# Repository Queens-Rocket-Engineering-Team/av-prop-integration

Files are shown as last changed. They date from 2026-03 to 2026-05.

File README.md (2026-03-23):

# Propulsion Integration Control Boards (Upper, Lower)
> 2025-2026 Season - Propulsion Integration Projects

-  Branch contains both board's **firmware**, **schematics**, and related **documentation and datasheets**.

### Folder Structure
- [`/Schematics`](./Schematics/) : PCB design files (KiCad V8)  
- [`/Firmware`](./Firmware/) : Arduino C/C++ code 
- [`/Datasheets`](./Datasheets/) : Datasheets and reference materials  

---

**Branch Created by:** Jeevan Sanchez

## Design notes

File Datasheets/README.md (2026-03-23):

# LC Board Datasheets

This directory contains datasheets, reference documents, and technical notes for LC board components, including:

- ESP32 MCU

- any interfaced hardware (sensors, CAN transceiver, etc.)

- software docs (external libs, etc.)

Filenames should follow the template: **`<type>_<partnumber>_<doc_type>`**, where **`<doc_type>`** indicates the document kind (e.g., `DS` = Datasheet, `DC` = Document, `C` = Chart).

- more documentation/notes/research can be found on the <a  href="https://www.notion.so/native/qret-ohyeah/Propulsion-Integration-Projects-261401792b9b805eae9ad54960dac8c4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">Notion<a/>

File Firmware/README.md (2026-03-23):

# Propulsion Integration Boards Firmware

This directory contains the firmware for both prop. integration boards. 

Including:

- board-specific firmware (testing, WiFi)
- shared firmware

 Firmware is developed in Arduino C/C++.

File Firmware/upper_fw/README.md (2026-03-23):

# Upper Board (Pheonix) Firmware

> This directory contains the firmware for the *upper* launch control board.

- Written in Arduino C/C++

---

### Configuring Arduino environment for ESP32-S3
 Ensure your [Arduino IDE](https://support.arduino.cc/hc/en-us/articles/360019833020-Download-and-install-Arduino-IDE) is up-to-date. 
- Open the *Preferences* menu (Ctrl+Comma), and add the link below into the *Additional Boards Manager* field. 
https://espressif.github.io/arduino-esp32/package_esp32_index.json 

- Navigate to the *Boards Manager* (Ctrl+Shift+B), and download the package **esp32** by **Espressif Systems**. 
- Once installed, open the *Tools* menu, and select the *Board* field, under the library you just installed (esp32), select the board: **ESP32S3 Dev Module**. 
- After selecting your board, you will see more fields under the *Tools* menu, find the field **USB CDC On Boot**, and **ENABLE** it. 
- Make sure you've selected the corrected port and upload!

### ADC Library used for reading from the onboard ADS131M04.
> https://github.com/icl-rocketry/ADS131M04-Lib/tree/master

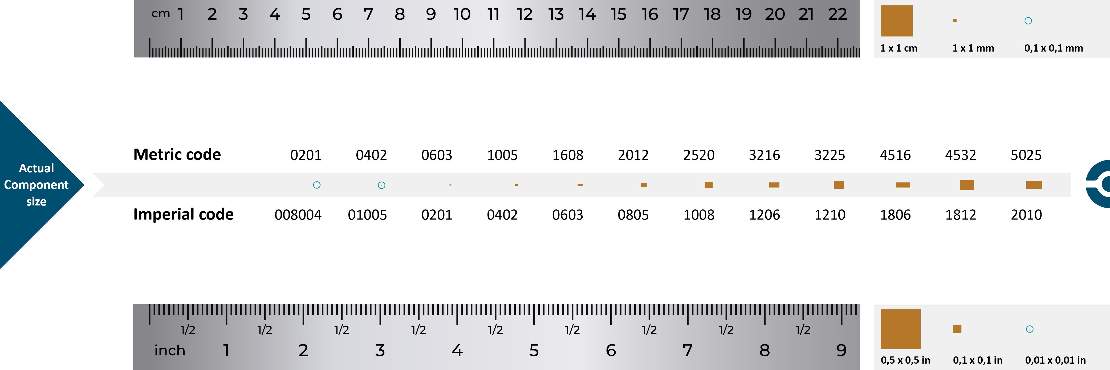
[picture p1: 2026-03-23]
Datasheets/SMD_SIZECHART_C.jpg

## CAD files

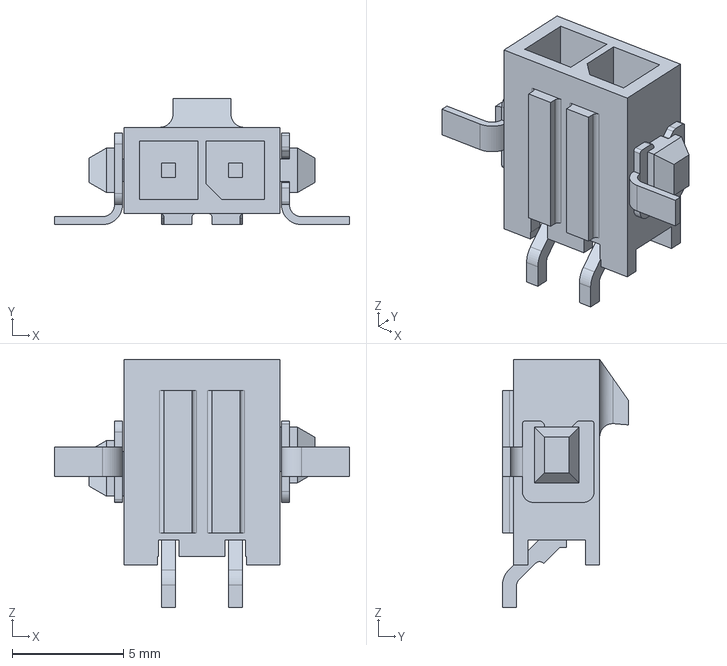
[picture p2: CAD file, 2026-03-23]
Schematics/dummy_24v_board/models/CONN_2-1445057-2_AMP.step
13.2 x 5.67 x 11.2 mm

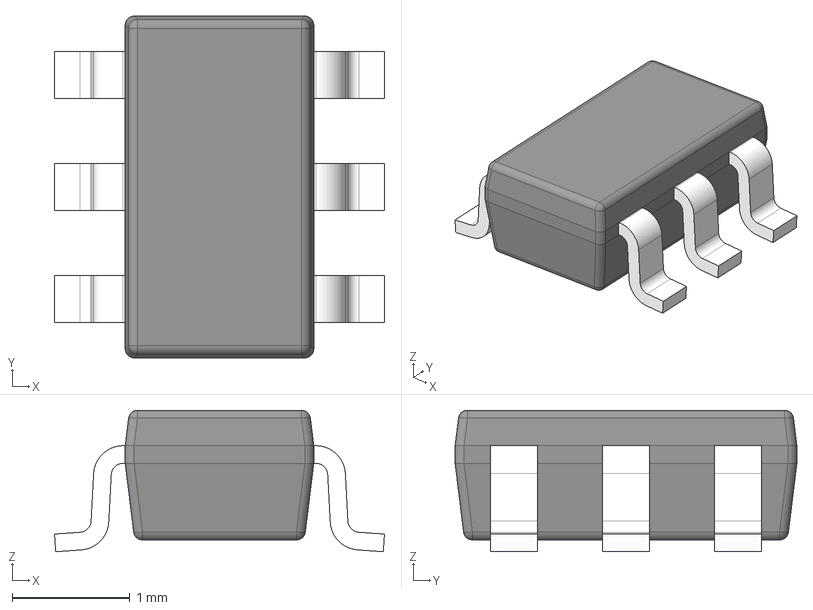
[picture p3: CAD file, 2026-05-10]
Schematics/hall_effect_board/models/TMAG5273A1QDBVT.stp
2.80 x 2.90 x 1.20 mm
BODY-SOT
LEAD-SOT x 6

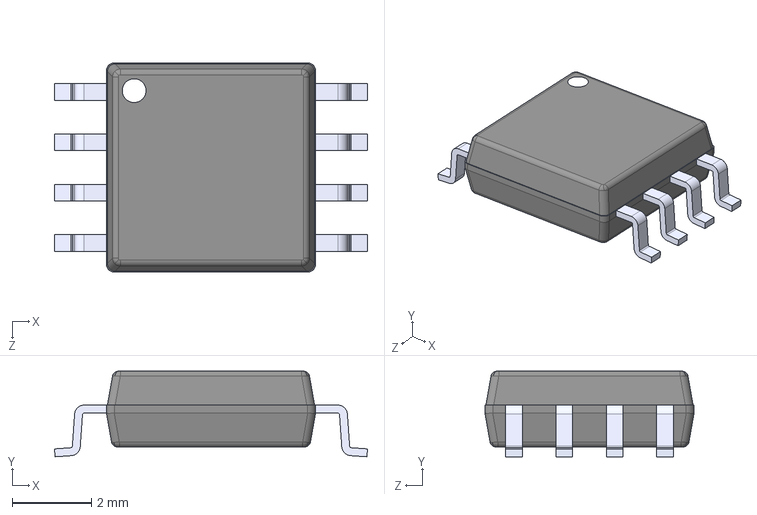
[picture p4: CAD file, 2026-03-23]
Schematics/lower_lc_board/models/W25Q128JVSIM.step
7.90 x 2.16 x 5.28 mm

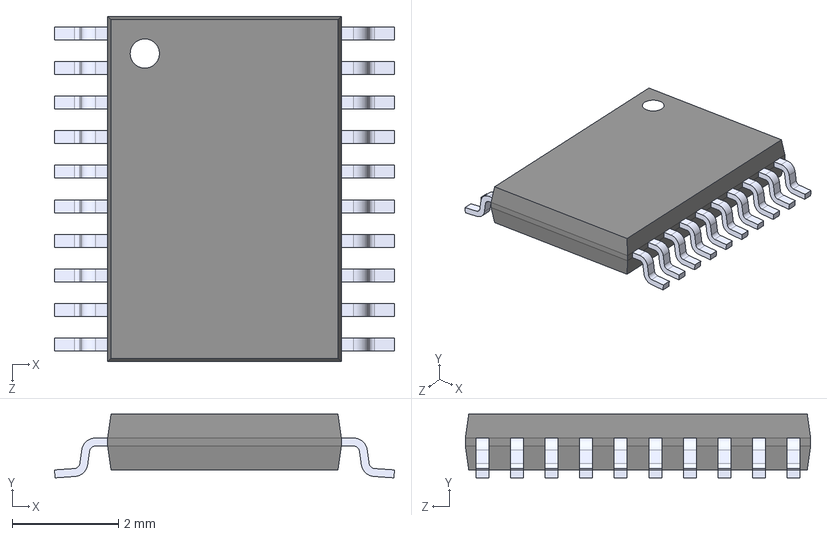
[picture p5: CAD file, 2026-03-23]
Schematics/shared_schematics/models/ADS131M04IPWR.step
6.40 x 1.20 x 6.50 mm

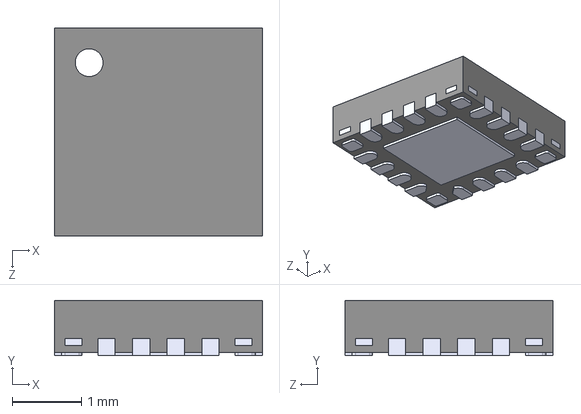
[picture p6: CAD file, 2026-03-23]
Schematics/lower_lc_board/models/CP2102N-A02-GQFN20.STEP
3.00 x 0.8 x 3.00 mm

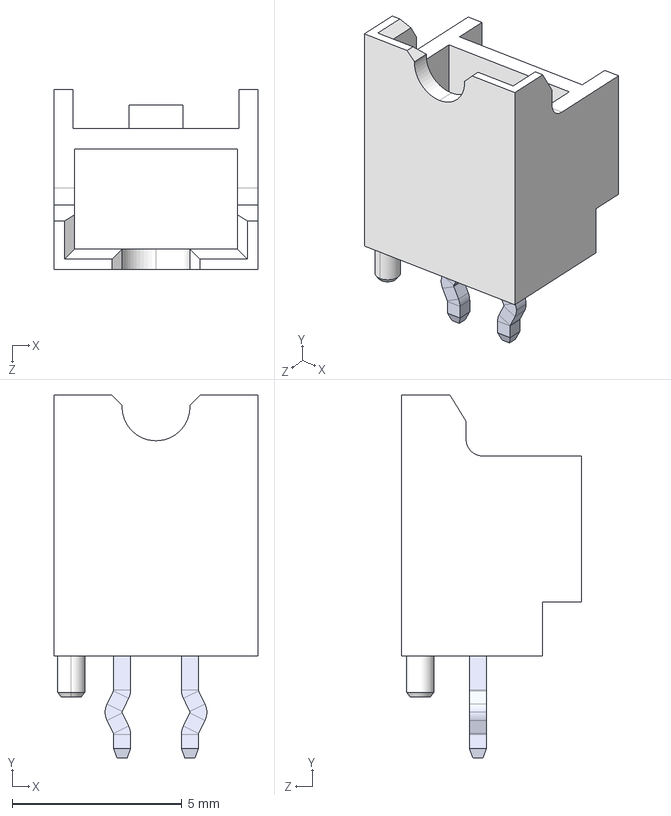
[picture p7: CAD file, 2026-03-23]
Schematics/lower_lc_board/models/B02B-PASK-1.STEP
6.00 x 10.7 x 5.30 mm
BxB-PASK(1)2-9_2boss
pin_bent x 2

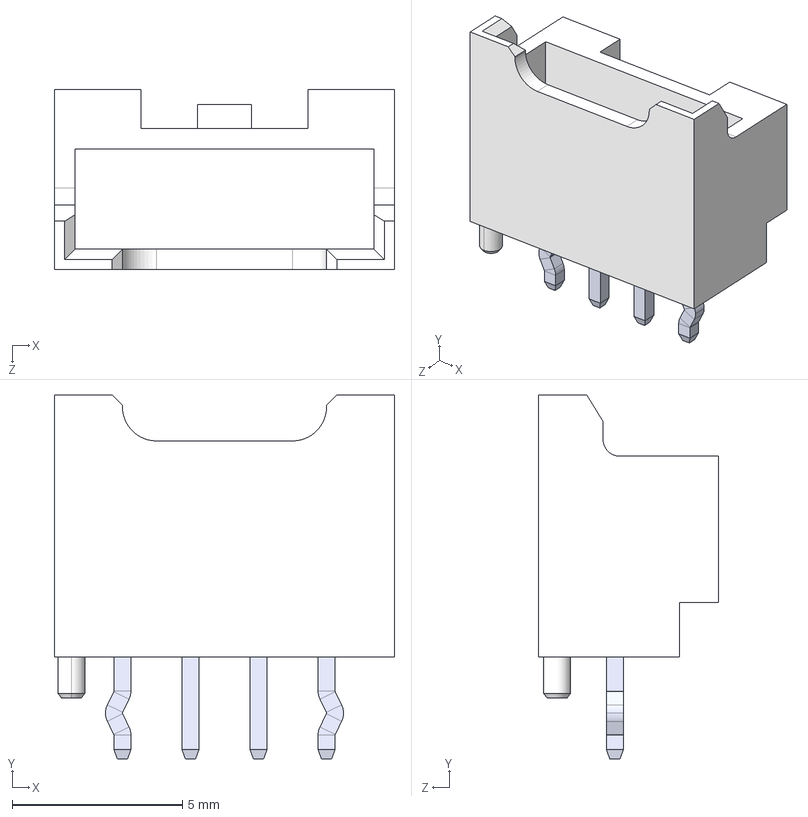
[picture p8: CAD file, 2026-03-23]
Schematics/lower_lc_board/models/B04B-PASK-1.STEP
10.00 x 10.7 x 5.30 mm
BxB-PASK(1)2-9_4boss
pin_bent x 2
pin x 2

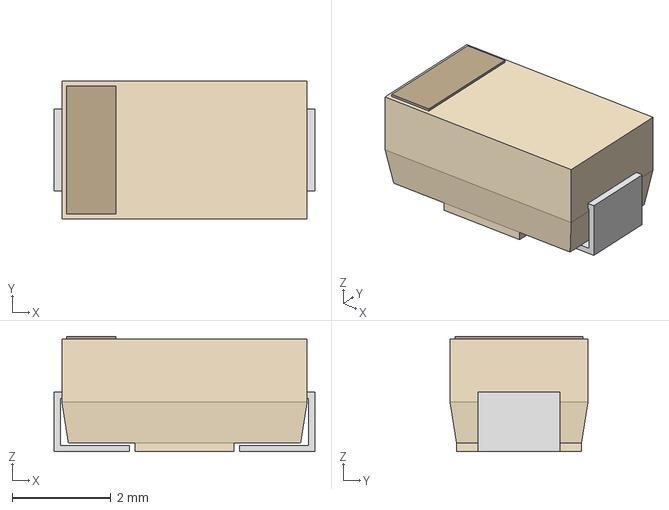
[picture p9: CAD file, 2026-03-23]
Schematics/shared_schematics/models/SMASeries_LTF.step
5.28 x 2.79 x 2.34 mm

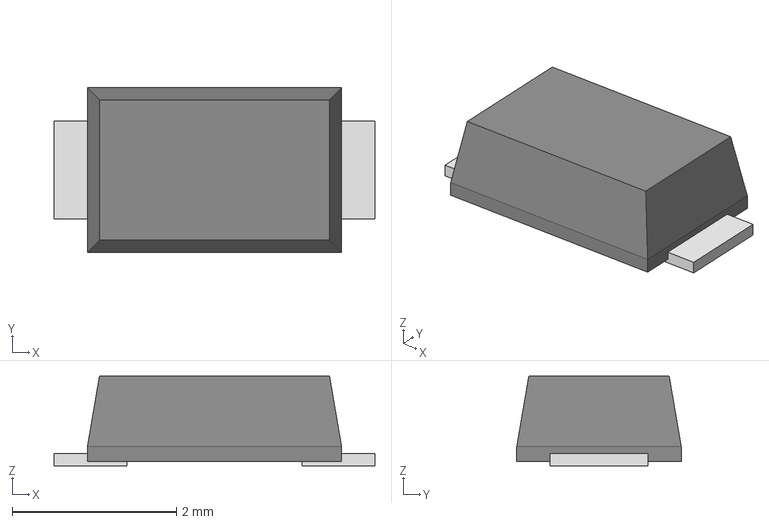
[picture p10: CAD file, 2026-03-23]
Schematics/shared_schematics/models/SOD-123F_LTF.step
3.91 x 2.01 x 1.09 mm

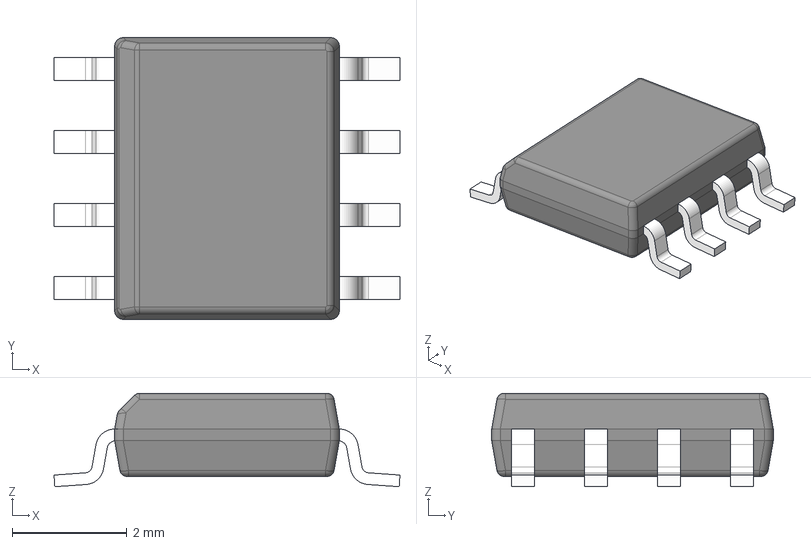
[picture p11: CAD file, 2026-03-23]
Schematics/shared_schematics/models/D0008A.stp
6.02 x 4.90 x 1.63 mm
BODY-SO
LEAD-D0008A x 8

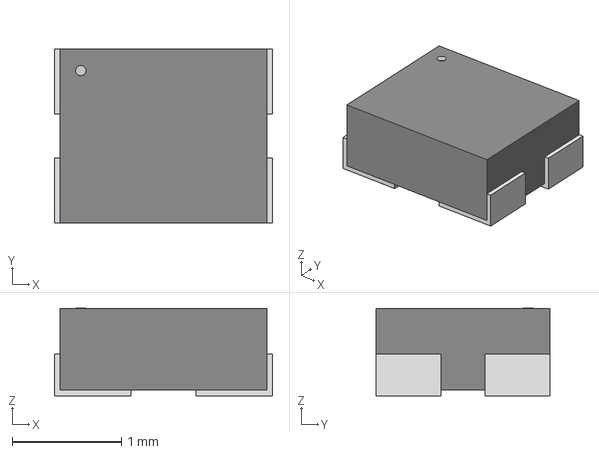
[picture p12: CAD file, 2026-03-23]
Schematics/shared_schematics/models/SON4_SIT1602-7_SIT.step
2.00 x 1.60 x 0.803 mm

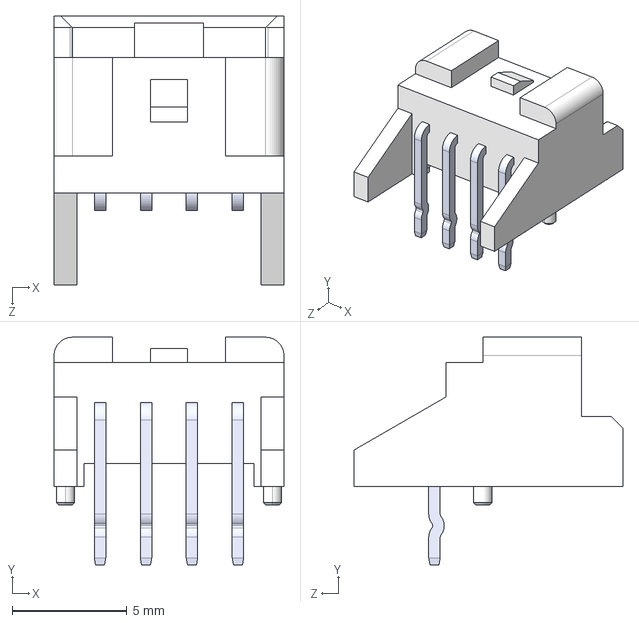
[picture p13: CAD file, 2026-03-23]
Schematics/shared_schematics/models/S04B-PASK-2.STEP
10.0 x 9.90 x 11.7 mm

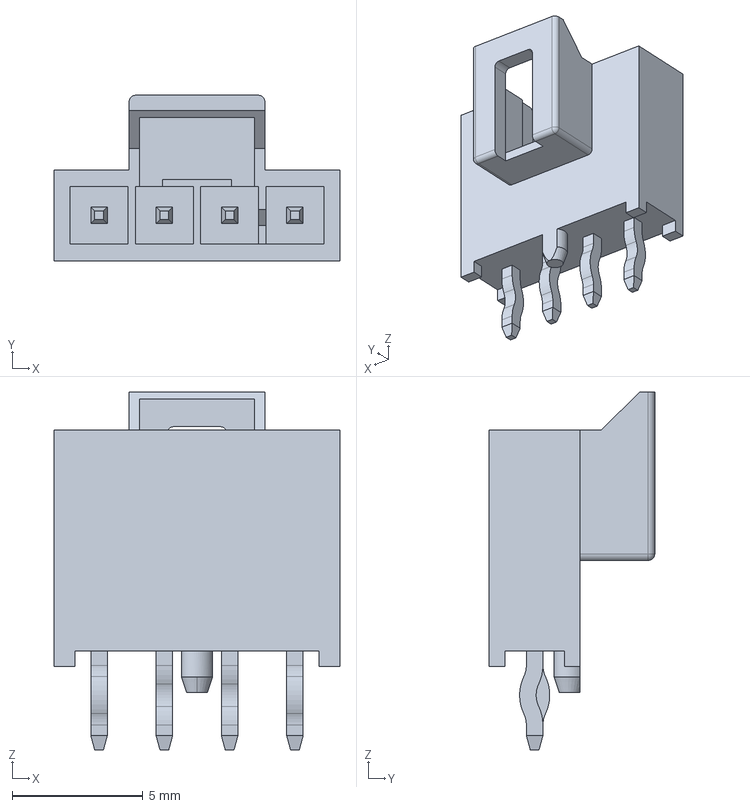
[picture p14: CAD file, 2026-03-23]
Schematics/hall_effect_board/models/1053091104.stp
10.9 x 6.34 x 13.7 mm

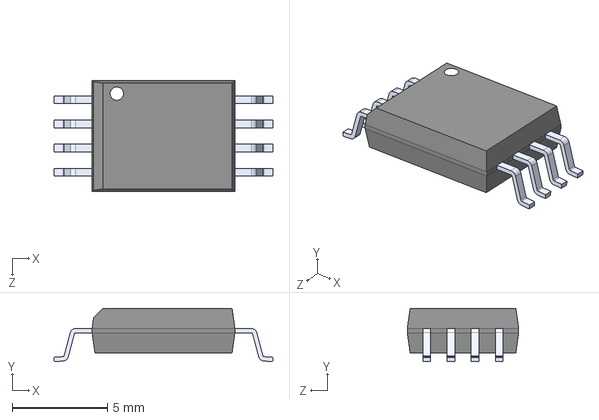
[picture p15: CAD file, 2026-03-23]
Schematics/shared_schematics/models/ISO1042BDWVR.step
11.5 x 2.80 x 5.85 mm

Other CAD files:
Schematics/lower_lc_board/models/m20-8890445r.stp
Schematics/shared_schematics/models/1053131102.step
Schematics/shared_schematics/models/1053091102.step
Schematics/lower_lc_board/models/430450602.stp
Schematics/shared_schematics/models/0679L0250-05.step
Schematics/shared_schematics/models/1053131104.stp
Schematics/shared_schematics/models/430450212.step
Schematics/shared_schematics/models/LM66100DCKR.STEP

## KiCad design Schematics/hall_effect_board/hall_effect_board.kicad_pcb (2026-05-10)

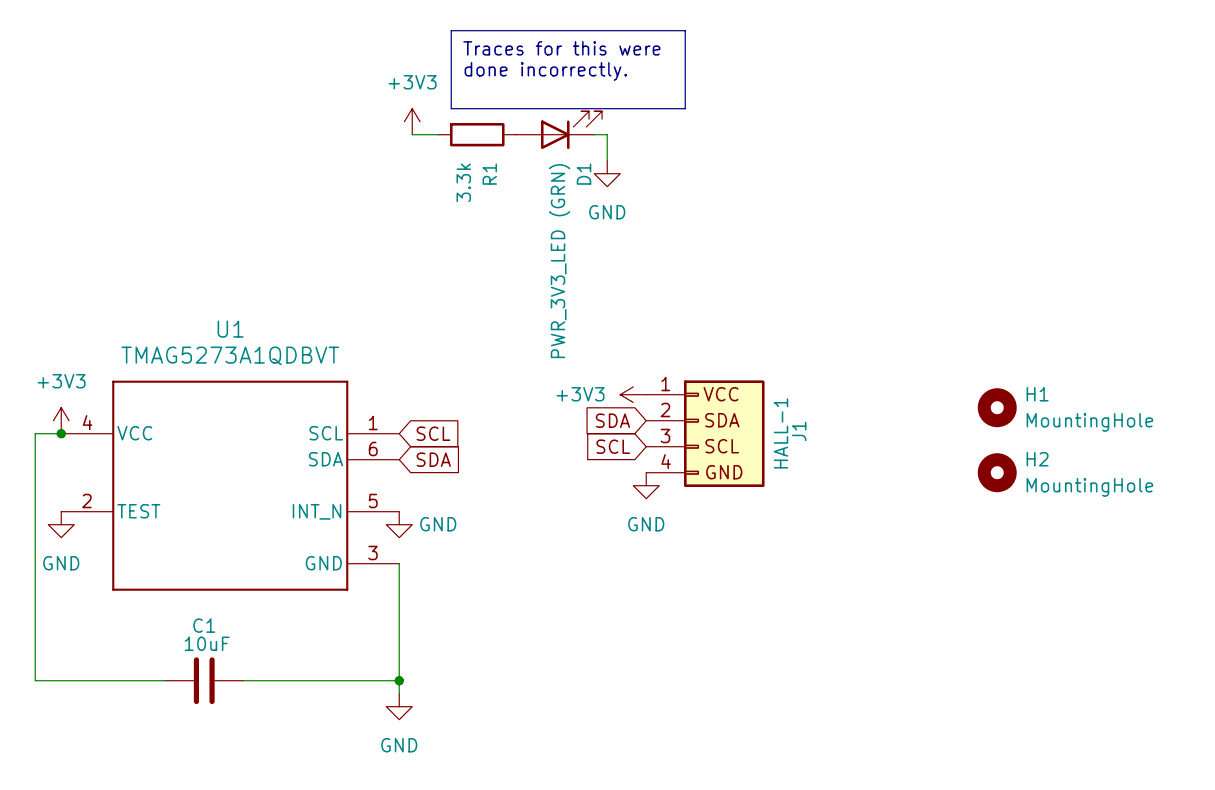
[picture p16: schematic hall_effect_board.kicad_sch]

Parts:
C1: 10uF; C_0805_2012Metric_Pad1.18x1.45mm_HandSolder; JLCSC C15850
D1: PWR_3V3_LED (GRN); LED_0603_1608Metric; JLCSC C2297
H1, H2: MountingHole; MountingHole_3.2mm_M3_ISO14580_Pad
J1: HALL-1; Molex_Nano-Fit_105313-xx04_1x04_P2.50mm_Horizontal; Digikey 455-S04B-PASK-2-ND
R1: 3.3k; R_0603_1608Metric; JLCSC C22978
U1: TMAG5273A1QDBVT; DBV0006A-IPC_A; Digikey 296-TMAG5273A1QDBVTCT-ND

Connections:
+3V3: C1.1, J1.1, R1.2, U1.4 (VCC)
GND: C1.2, D1.1 (K), J1.4, U1.2 (TEST), U1.3 (GND), U1.5 (INT_N)
unnamed: D1.2 (A), R1.1
SCL: J1.3, U1.1 (SCL)
SDA: J1.2, U1.6 (SDA)

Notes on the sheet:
Traces for this were done incorrectly.

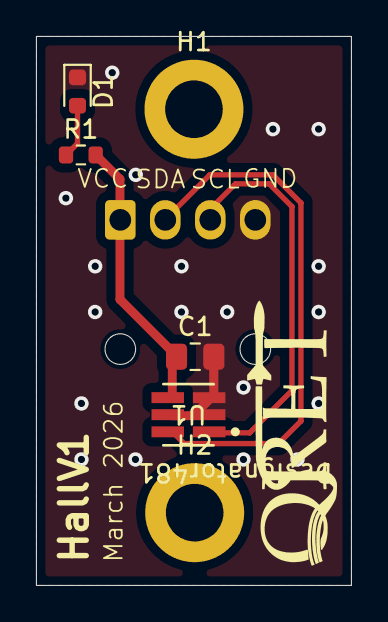
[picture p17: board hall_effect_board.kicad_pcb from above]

Board: 2 copper layers, 17.5 x 30.5 mm, 7 parts (1 on the bottom side), 5 nets.

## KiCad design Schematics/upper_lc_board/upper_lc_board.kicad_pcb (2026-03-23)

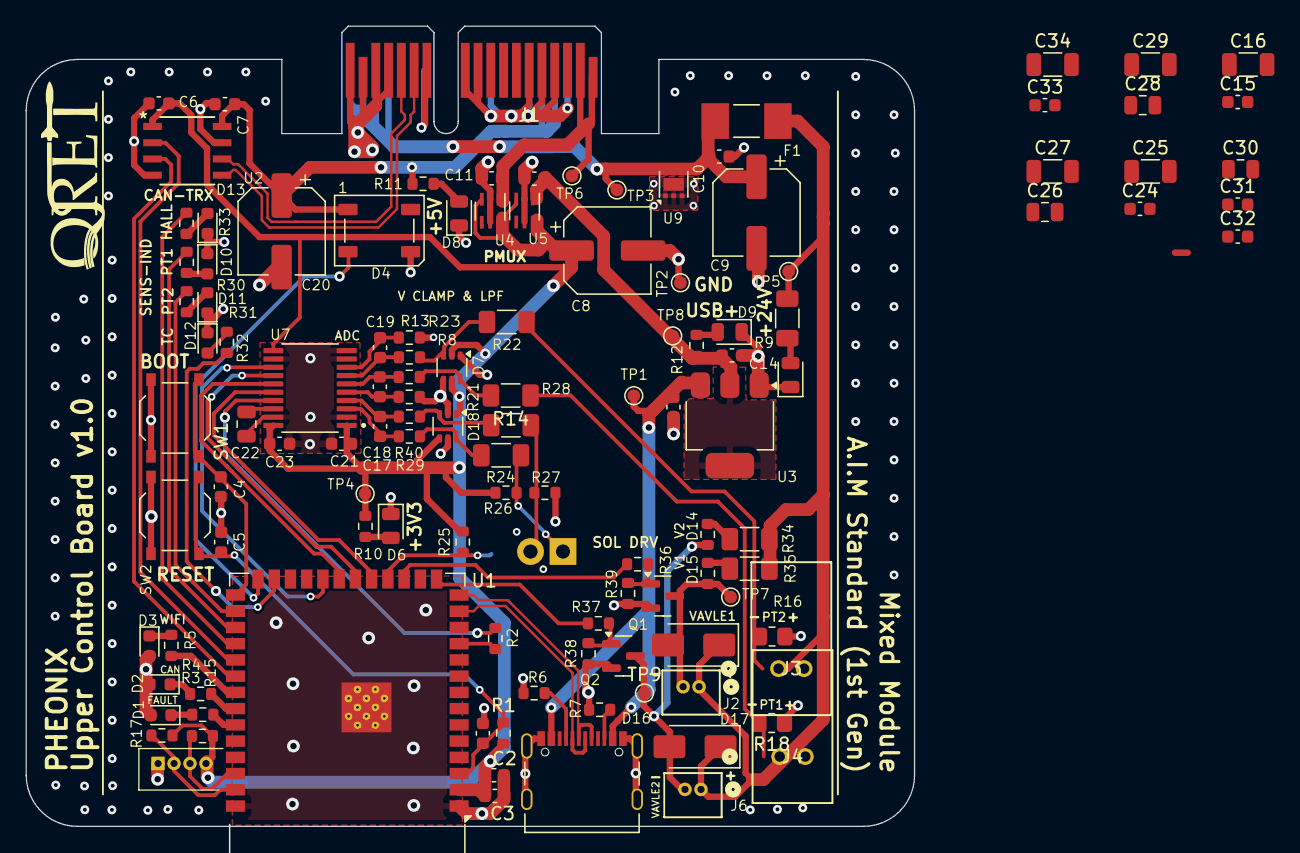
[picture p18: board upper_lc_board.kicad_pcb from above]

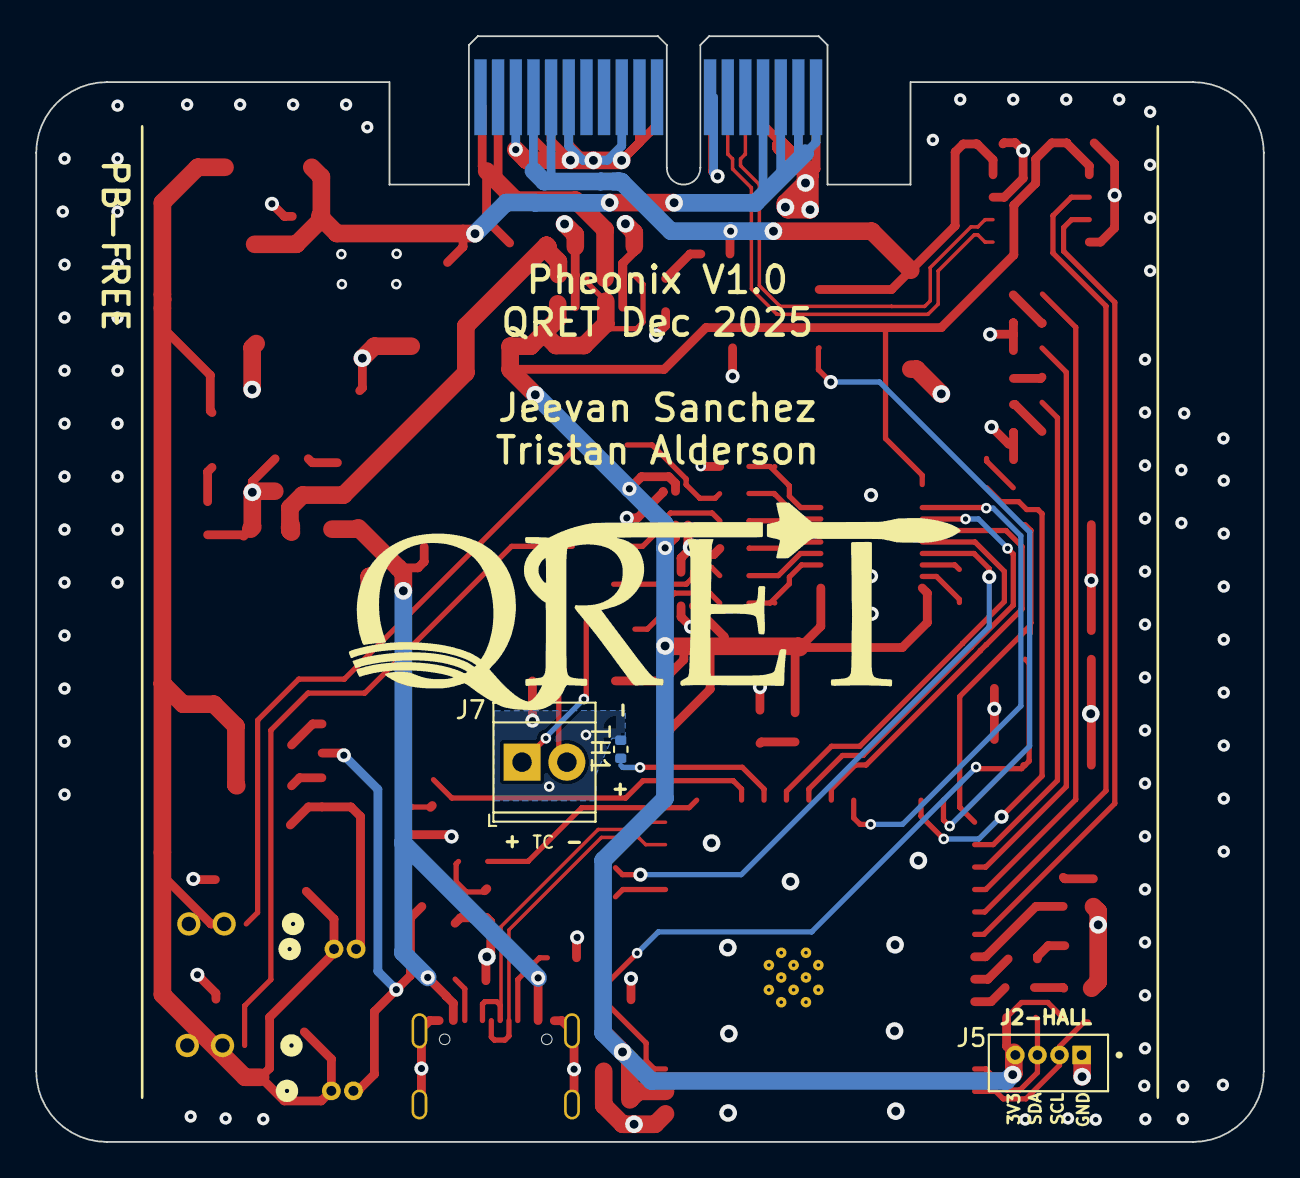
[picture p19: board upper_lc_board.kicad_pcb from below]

Board: 4 copper layers, 69.5 x 62.6 mm, 121 parts (3 on the bottom side), 73 nets.

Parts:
C1, C11, C12, C21, C23: 1uF; C_0603_1608Metric
C2, C4, C5, C6, C7, C10, C33: 0.1uF; C_0603_1608Metric
C3, C13, C14: 10uF; C_0603_1608Metric
C8, C9, C20: 100uF; CP_Elec_6.3x5.9
C15, C24: 0.1uF_50V; C_0603_1608Metric
C16, C25: 10uF_50V; C_1206_3216Metric
C17, C18, C19: 10nF; C_0603_1608Metric
C22: 220 nF; C_0805_2012Metric
C26, C28, C30: 0.1uF; C_0805_2012Metric
C27, C29: 10uF; C_1206_3216Metric
C31, C32: 1nF; C_0603_1608Metric
C34: 1uF_10V; C_1206_3216Metric
D1: FAULT_LED; LED_0603_1608Metric
D2: CAN_LED; LED_0603_1608Metric
D3: WIFI_LED; LED_0603_1608Metric
D4: SYS_LED_WS2812B; LED_WS2812B_PLCC4_5.0x5.0mm_P3.2mm
D5: PWR_24V_LED (GRN); LED_0805_2012Metric
D6: PWR_3V3_LED (GRN); LED_0805_2012Metric
D7, D18: BAV199DW; SOT-363_SC-70-6
D8: PWR_5V_LED (GRN); LED_0805_2012Metric
D9: USB_LED (GRN); LED_0805_2012Metric
D10, D11, D12, D13: LED; LED_0603_1608Metric
D14: SOL2_LED (YELW); R_0603_1608Metric
D15: SOL1_LED (YELW); R_0603_1608Metric
D16, D17: SS34; D_SMA
F1: Fuse; FUSC6125X279N
J1: Stack Male Edge Connector; BUS_PCIexpress_x1
J2, J6: SOL_CONN; CONN02_530470260_MOL
J3, J4: PT1; CONN2_S02B-PASK-2_JST
J5: HALL; MOLEX_53047-0460
J7: Screw_Terminal_01x02; TerminalBlock_TE_282834-2_1x02_P2.54mm_Horizontal
J8: USB_C_Female_USB2_Small; USB_C_DB-108PWB
NT1: GND-TIE; NetTie-2_SMD_Pad0.5mm
Q1, Q2: AO3400A; SOT-23
R1, R25: 10k; R_0603_1608Metric
R2: 33; R_0603_1608Metric
R3, R4, R5, R10, R12, R30, R31, R32, R33: 150; R_0603_1608Metric
R6, R7: 5.1k; R_0603_1608Metric
R8, R13, R29, R36, R37, R40: 200; R_0603_1608Metric
R9, R34, R35: 4.7k; R_1206_3216Metric_Pad1.30x1.75mm_HandSolder
R11: 510; R_0603_1608Metric
R14, R22, R24, R28: 1k; R_1206_3216Metric_Pad1.30x1.75mm_HandSolder
R15, R17: 2.2k; R_0603_1608Metric
R16, R18: 165; R_0805_2012Metric_Pad1.20x1.40mm_HandSolder
R21, R23: 1.2k; R_0603_1608Metric
R26, R27: 1M; R_0603_1608Metric
R38, R39: 100k; R_0603_1608Metric
SW1: SW_ESP_BOOT_MODE; SW_Push_1P1T_XKB_TS-1187A
SW2: SW_ESP_RESET; SW_Push_1P1T_XKB_TS-1187A
TH1: Thermistor; R_0402_1005Metric
TP1: 5V_USB; TestPoint_Pad_D1.0mm
TP2: GND; TestPoint_Pad_D1.0mm
TP3: 24V_BP; TestPoint_Pad_D1.0mm
TP4: 3V3; TestPoint_Pad_D1.0mm
TP5: 24V; TestPoint_Pad_D1.0mm
TP6: 3V3_BP; TestPoint_Pad_D1.0mm
TP7: VALVE1_OUT_TP; TestPoint_Pad_D1.0mm
TP8: 3V3_USB; TestPoint_Pad_D1.0mm
TP9: VALVE2_OUT_TP; TestPoint_Pad_D1.0mm
U1: ESP32-S3-WROOM-1-N16; ESP32-S3-WROOM-1
U2: ISO1044BDR; SOIC_1044BDR_TEX
U3: AMS1117; SOT-223-3_TabPin2
U4, U5: ID_LM66100DCKR; SC-70-6
U7: ADC_ADS131M04IPWR; SOP65P640X120-20N
U9: TVS3300DRV; WSON-6-1EP_2x2mm_P0.65mm_EP1x1.6mm

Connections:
5V_USB: C13.1, J8.A4 (VBUS), J8.A9 (VBUS), J8.B4 (VBUS), J8.B9 (VBUS), TP1.1, U3.3 (VI)
+3V3: C2.1, C3.1, C6.1, C8.1, C21.2, C23.2, C33.1, C34.1, D7.2 (K2), D7.5 (K4), D18.2 (K2), D18.5 (K4), J5.4, R1.1, R10.2, R15.2, R17.1, R25.2, R26.1, TP4.1, U1.2 (3V3), U2.1 (VCC1), U4.3 (*CE), U4.6 (VOUT), U5.3 (*CE), U5.6 (VOUT), U7.1 (AVDD), U7.11 (~SYNC/~RESET), U7.20 (DVDD)
+5V: C7.1, C20.1, D4.1 (VDD), J1.A4 (5.0V_A), J1.A5 (5.0V_A), R11.2, U2.8 (VCC2)
+24V: C15.1, C16.1, C24.1, C25.1, D16.1 (K), D17.1 (K), F1.1, J2.1, J6.1, R9.2, R34.2, R35.2, TP5.1
+24V_BP: C10.1, J1.A15 (24V_C), J1.A16 (24V_C), J1.A17 (24V_C), J1.A18 (24V_C), TP3.1, U9.4 (IN), U9.5 (IN), U9.6 (IN)
/ESP Breakout Cirucitry/ESP32_EN: C1.1, C5.2, R1.2, SW2.2, U1.3 (EN)
/ESP Breakout Cirucitry/ESP32_IO0: C4.2, SW1.2, U1.27 (IO0)
/ESP Breakout Cirucitry/GPIO_18: R2.1, U1.11 (IO18)
/ESP Breakout Cirucitry/GPIO_38: U1.31 (IO38), U2.2 (TXD)
/ESP Breakout Cirucitry/GPIO_39: U1.32 (IO39), U2.3 (RXD)
/ESP Breakout Cirucitry/GPIO_40: R5.1, U1.33 (IO40)
/ESP Breakout Cirucitry/GPIO_41: R4.1, U1.34 (IO41)
/ESP Breakout Cirucitry/GPIO_42: R3.1, U1.35 (IO42)
/ESP Breakout Cirucitry/GPIO_45: D4.2 (DOUT), U1.26 (IO45)
/ESP Breakout Cirucitry/USB_N: J8.A7 (D-), J8.B7 (D-), U1.13 (USB_D-)
/ESP Breakout Cirucitry/USB_P: J8.A6 (D+), J8.B6 (D+), U1.14 (USB_D+)
/Power Circuitry/3V3_BP: C11.2, J1.A1 (3.3V_A), J1.A2 (3.3V_A), TP6.1, U4.1 (VIN)
/Power Circuitry/3V3_USB: C12.1, C14.1, R12.1, TP8.1, U3.2 (VO), U5.1 (VIN)
/Sensor Circuitry/PT1: J4.2, R14.1, R18.2
/Sensor Circuitry/PT1_CLAMPED: C18.2, R13.1, U7.6 (AIN1P)
/Sensor Circuitry/PT2: J3.2, R16.2, R22.1
/Sensor Circuitry/PT2_CLAMPED: C19.2, R8.1, U7.7 (AIN2P)
/Sensor Circuitry/PT-1/VIN: C26.1, C27.1, J4.1
/Sensor Circuitry/PT-2/VIN: C28.1, C29.1, J3.1
/Sensor Circuitry/TC_N: C30.1, C32.2, J7.2, R27.1, R28.2
/Sensor Circuitry/TC_N_CLAMPED: C17.1, R40.2, U7.4 (AIN0N)
/Sensor Circuitry/TC_P: C30.2, C31.2, J7.1, R24.2, R26.2
/Sensor Circuitry/TC_P_CLAMPED: C17.2, R29.2, U7.3 (AIN0P)
ADC_CLKIN: R2.2, U7.17 (CLKIN)
ADC_DREADY: U1.22 (IO14), U7.13 (~DRDY)
ADC_MISO: U1.21 (IO13), U7.15 (DOUT)
ADC_MOSI: U1.19 (IO11), U7.16 (DIN)
ADC_SCLK: U1.20 (IO12), U7.14 (SCLK)
CAN_+: J1.B14 (CAN_H), U2.6 (CANH)
CAN_-: J1.B13 (CAN_L), U2.5 (CANL)
GND: C1.2, C2.2, C3.2, C4.1, C5.1, C6.2, C7.2, C8.2, C9.2, C10.2, C11.1, C12.2, C13.2, C14.2, C15.2, C16.2, C20.2, C23.1, C24.2, C25.2, C33.2, C34.2, D1.2 (A), D2.2 (A), D3.2 (A), D4.3 (VSS), D5.1 (K), D6.1 (K), D8.1 (K), D9.1 (K), D10.1 (K), D11.1 (K), D12.1 (K), D13.1 (K), J1.A3 (GND_A), J1.A6 (GND_A), J1.A9 (GND_B), J1.A12 (GND_B), J1.B4 (GND_A), J1.B5 (GND_A), J1.B6 (GND_A), J1.B10 (GND_B), J1.B11 (GND_B), J1.B12 (GND_B), J1.B15 (GND_C), J1.B16 (GND_C), J1.B17 (GND_C), J1.B18 (GND_C), J5.1, J8.A1 (GND), J8.A12 (GND), J8.B1 (GND), J8.B12 (GND), J8.S1 (SHIELD), NT1.2, Q1.2 (S), Q2.2 (S), R6.2, R7.2, R38.1, R39.1, SW1.1, SW2.1, TP2.1, U1.1 (GND), U1.40 (GND), U1.41 (GND), U2.4 (GND1), U2.7 (GND2), U3.1 (ADJ), U4.2 (GND), U4.5 (ST), U5.2 (GND), U5.5 (ST), U7.12 (~CS), U7.19 (DGND), U9.1 (GND), U9.2 (GND), U9.3 (GND), U9.7 (GND)
GNDA: C21.1, C22.2, C26.2, C27.2, C28.2, C29.2, C31.1, C32.1, D7.1 (A1), D7.4 (A3), D18.1 (A1), D18.4 (A3), NT1.1, R16.1, R18.1, R21.1, R23.1, R27.2, TH1.2, U7.2 (AGND), U7.9 (AIN3N), U7.10 (AIN3P)
HALL_LED: R33.1, U1.30 (IO37)
HALL_SCL: J5.2, R17.2, U1.39 (IO1)
HALL_SDA: J5.3, R15.1, U1.38 (IO2)
unnamed: C9.1, F1.2
unnamed: D1.1 (K), R3.2
unnamed: D2.1 (K), R4.2
unnamed: D3.1 (K), R5.2
unnamed: D5.2 (A), R9.1
unnamed: D6.2 (A), R10.1
unnamed: D7.6 (K3A4), R13.2, R14.2
unnamed: D7.3 (K1A2), R8.2, R22.2
unnamed: D8.2 (A), R11.1
unnamed: D9.2 (A), R12.2
unnamed: D10.2 (A), R30.2
unnamed: D11.2 (A), R31.2
unnamed: D12.2 (A), R32.2
unnamed: D13.2 (A), R33.2
unnamed: D14.2 (A), R34.1
unnamed: D15.2 (A), R35.1
unnamed: D18.6 (K3A4), R24.1, R29.1
unnamed: D18.3 (K1A2), R28.1, R40.1
unnamed: J8.A5 (CC1), R6.1
unnamed: J8.B5 (CC2), R7.1
unnamed: Q1.1 (G), R36.1, R39.2
unnamed: Q2.1 (G), R37.1, R38.2
unnamed: C18.1, R21.2, U7.5 (AIN1N)
unnamed: C19.1, R23.2, U7.8 (AIN2N)
unnamed: C22.1, U7.18 (CAP)
PT1_LED: R30.1, U1.29 (IO36)
PT2_LED: R31.1, U1.28 (IO35)
SOL1_RET: D15.1 (K), D16.2 (A), J2.2, Q1.3 (D)
SOL2_RET: D14.1 (K), D17.2 (A), J6.2, Q2.3 (D)
TC_LED: R32.1, U1.25 (IO48)
TEMP_SENSE: R25.1, TH1.1, U1.18 (IO10)
VALVE1_CTRL: R36.2, U1.17 (IO9)
VALVE2_CTRL: R37.2, U1.15 (IO3)

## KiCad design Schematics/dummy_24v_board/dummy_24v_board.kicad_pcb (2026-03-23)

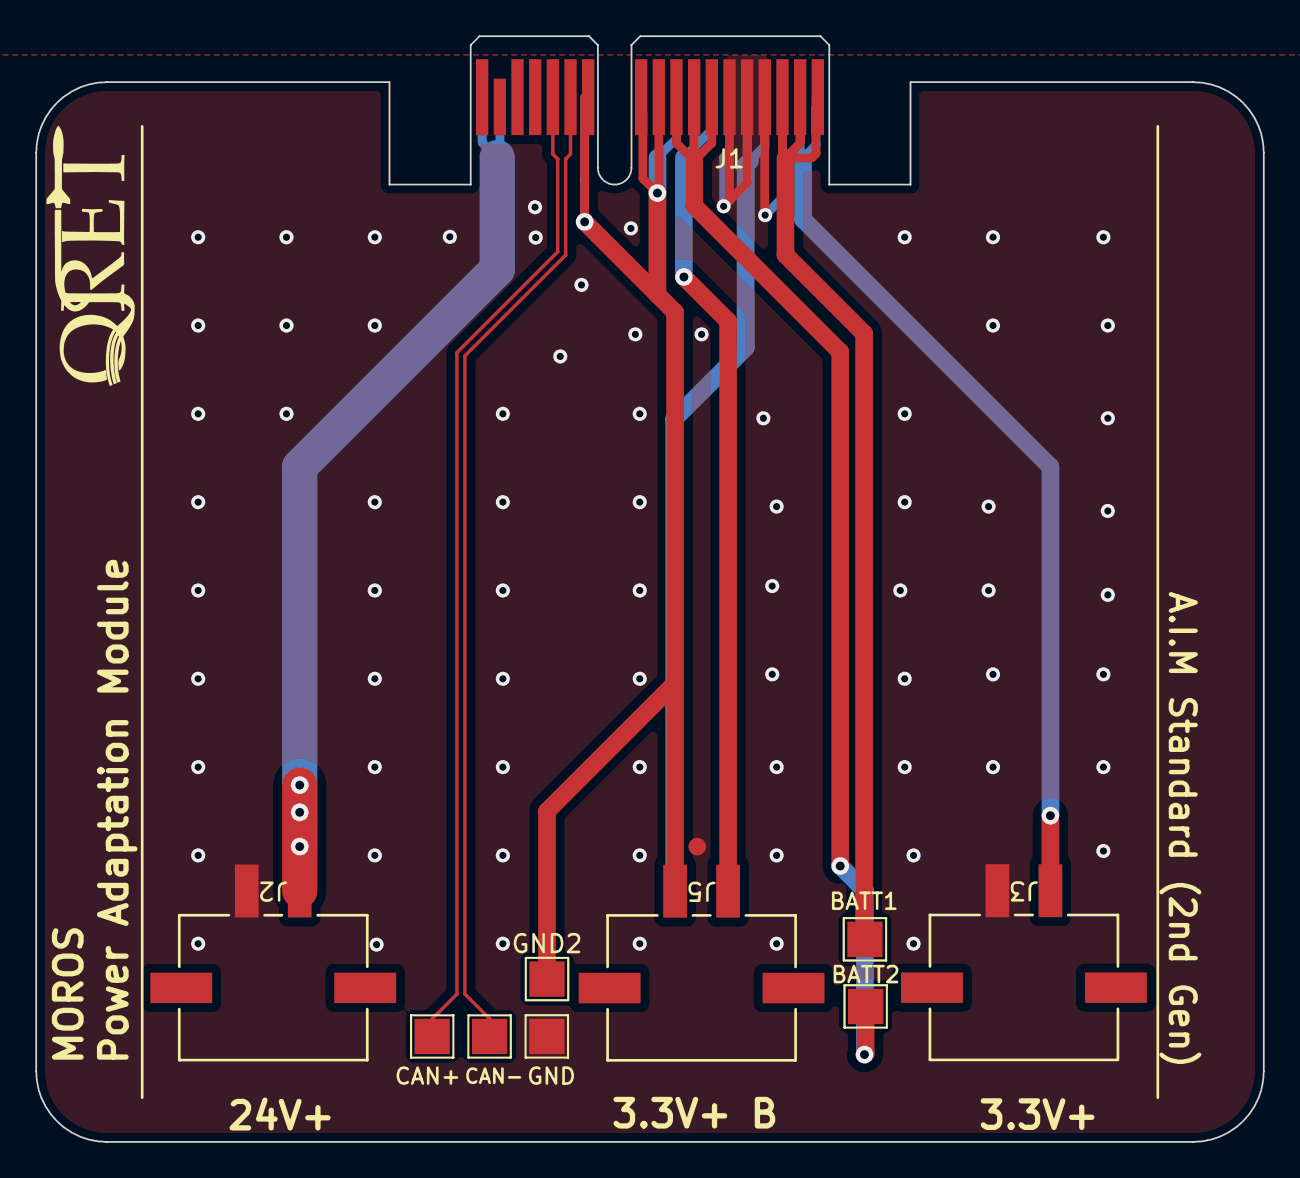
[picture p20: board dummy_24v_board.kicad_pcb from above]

Board: 2 copper layers, 69.5 x 62.6 mm, 11 parts (1 on the bottom side), 10 nets.

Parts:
BATT1, BATT2: TestPoint; TestPoint_Pad_2.0x2.0mm
CAN+: TestPoint; TestPoint_Pad_2.0x2.0mm
CAN-: TestPoint; TestPoint_Pad_2.0x2.0mm
GND, GND2: TestPoint; TestPoint_Pad_2.0x2.0mm
J1: Stack Male Edge Connector; BUS_PCIexpress_x1
J2, J3, J4, J5: Conn_01x02_Socket; CONN_2-1445057-2_TYCO

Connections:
+3.3V: J1.A1 (3.3V_A), J1.A2 (3.3V_A), J3.1
+3.3V_B: J1.A7 (3.3V_B), J1.A8 (3.3V_B), J5.1
+5V: J1.A4 (5.0V_A), J1.A5 (5.0V_A), J4.1
+24V: J1.A17 (24V_A), J1.A18 (24V_A), J2.1
/BATT_1: BATT1.1, J1.B1 (BATT_A), J1.B2 (BATT_A), J1.B3 (BATT_A)
/BATT_2: BATT2.1, J1.B7 (BATT_B), J1.B8 (BATT_B), J1.B9 (BATT_B)
CAN_+: CAN+.1, J1.B14 (CAN_H)
CAN_-: CAN-.1, J1.B13 (CAN_L)
GND: GND.1, J1.A3 (GND_A), J1.A6 (GND_A), J1.B4 (GND_A), J1.B5 (GND_A), J1.B6 (GND_A), J2.2, J3.2, J4.2
GND2: GND2.1, J1.A9 (GND_B), J1.A12 (GND_B), J1.B10 (GND_B), J1.B11 (GND_B), J1.B12 (GND_B), J5.2

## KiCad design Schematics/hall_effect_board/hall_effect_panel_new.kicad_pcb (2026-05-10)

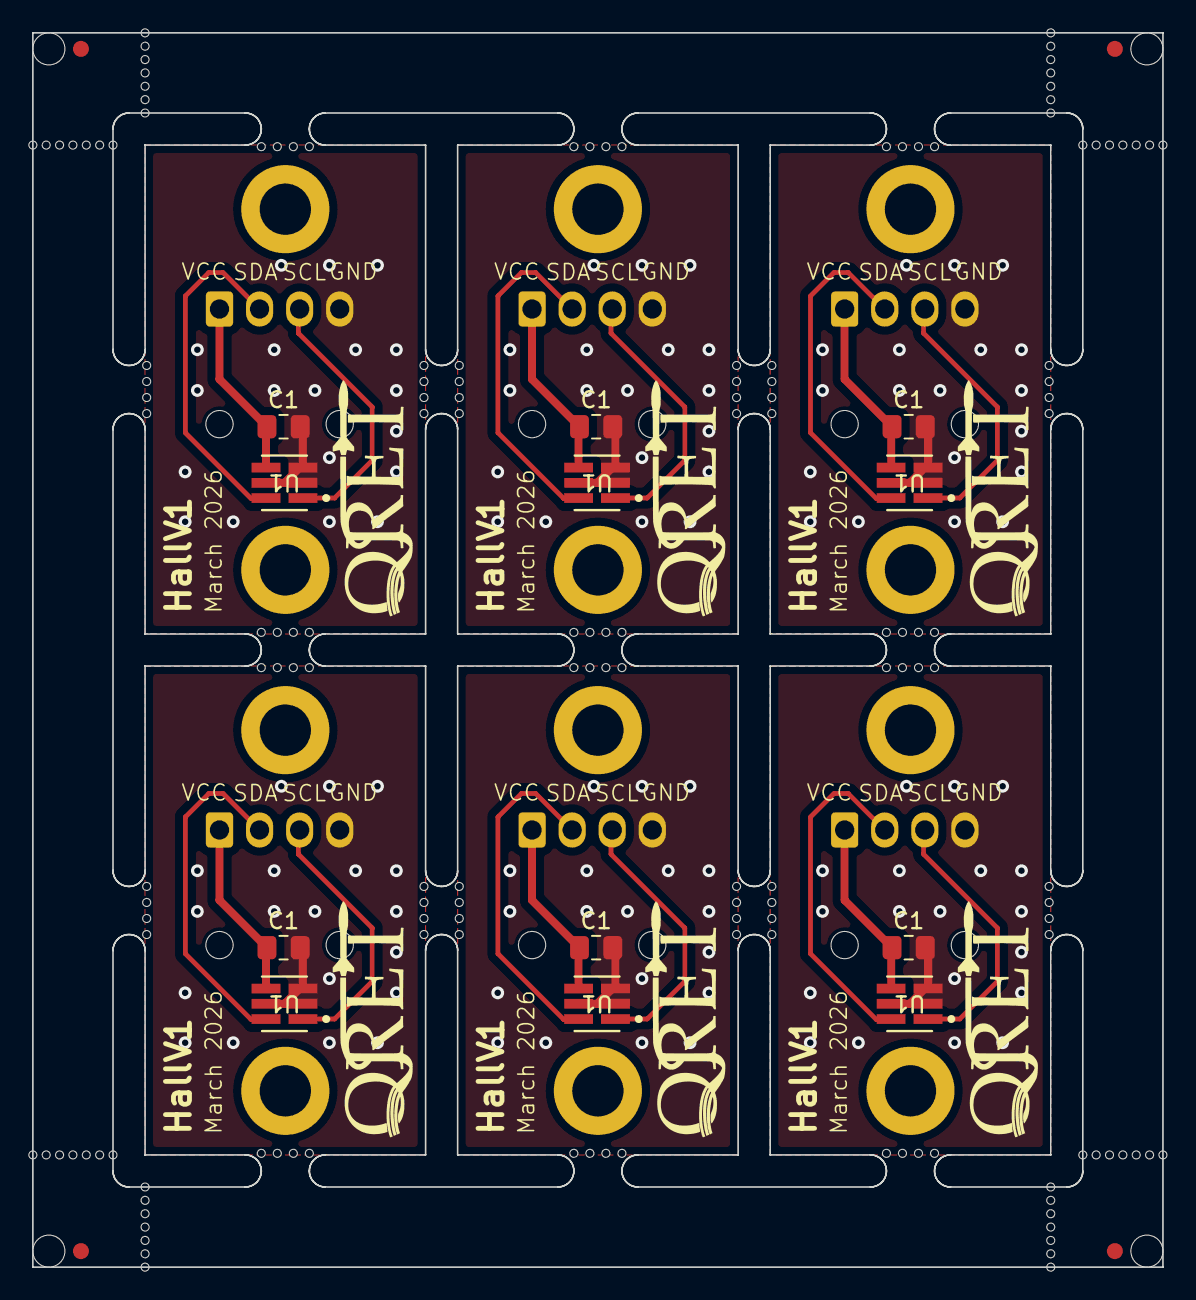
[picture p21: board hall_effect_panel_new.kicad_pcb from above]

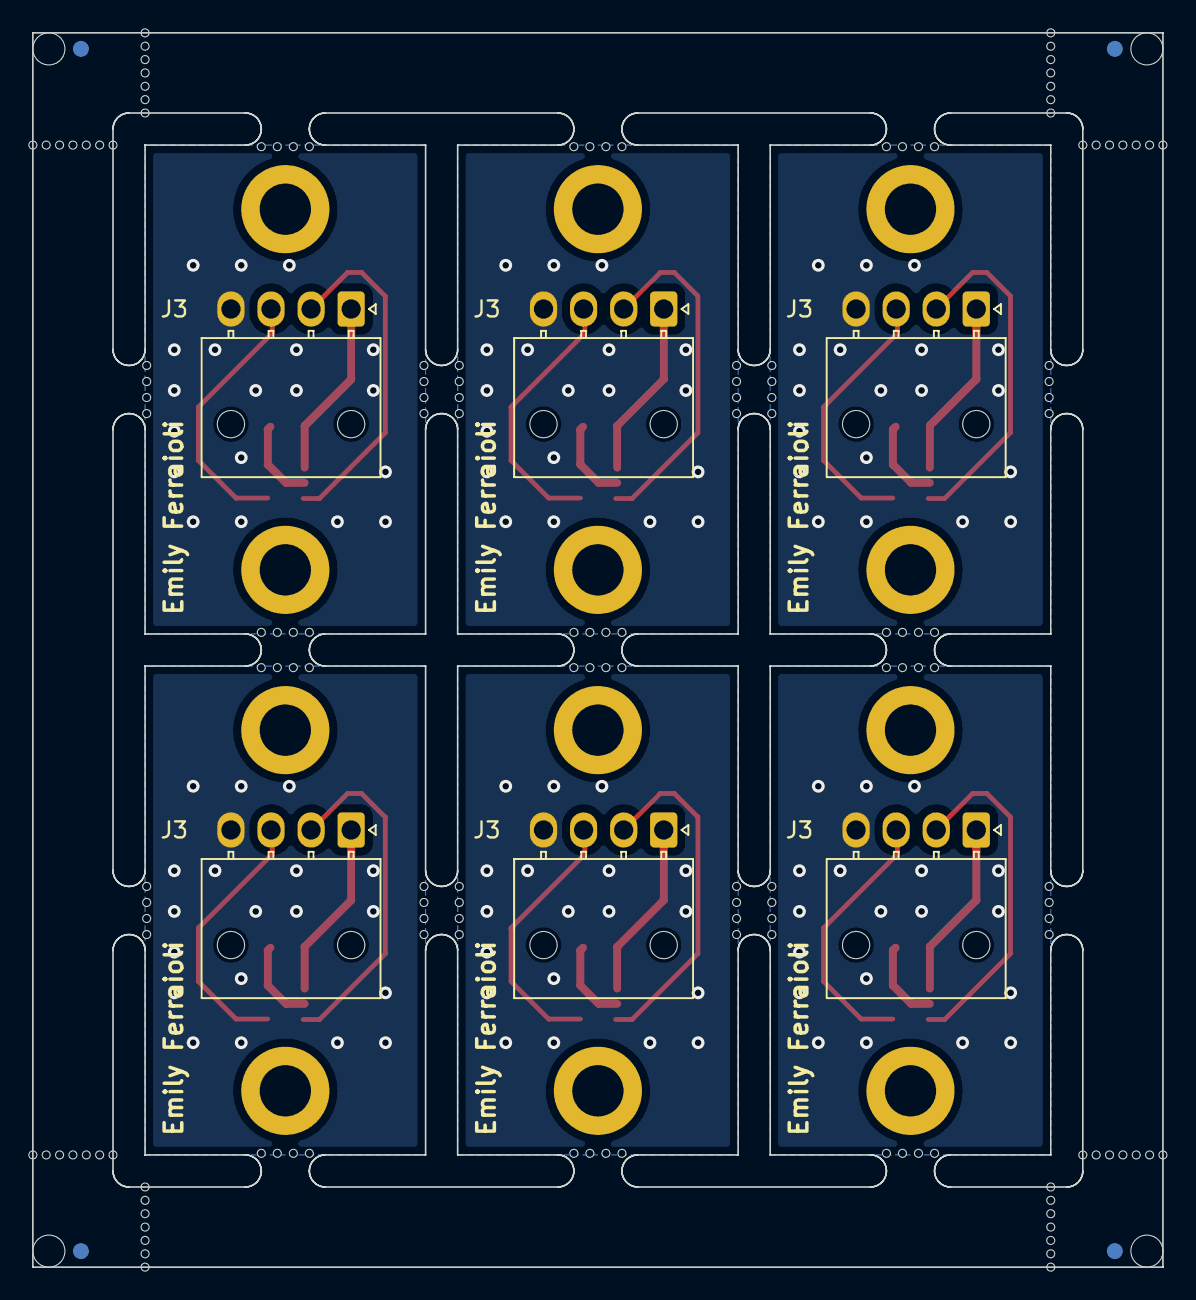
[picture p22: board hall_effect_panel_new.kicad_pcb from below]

Board: 2 copper layers, 70.5 x 77.0 mm, 194 parts (10 on the bottom side), 24 nets.

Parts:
C1, C1#2, C1#3, C1#4, C1#5, C1#6: 0.01uF; C_0805_2012Metric_Pad1.18x1.45mm_HandSolder
H1, H1#2, H1#3, H1#4, H1#5, H1#6, H2, H2#2, H2#3, H2#4, H2#5, H2#6: MountingHole; MountingHole_3.2mm_M3_ISO14580_Pad
J3, J3#2, J3#3, J3#4, J3#5, J3#6: HALL-1; Molex_Nano-Fit_105313-xx04_1x04_P2.50mm_Horizontal
KiKit_FID_B_1, KiKit_FID_B_2, KiKit_FID_B_3, KiKit_FID_B_4: Fiducial
KiKit_FID_T_1, KiKit_FID_T_2, KiKit_FID_T_3, KiKit_FID_T_4: Fiducial
KiKit_MB_1_1, KiKit_MB_1_2, KiKit_MB_1_3, KiKit_MB_1_4, KiKit_MB_2_1, KiKit_MB_2_2, KiKit_MB_2_3, KiKit_MB_2_4, KiKit_MB_3_1, KiKit_MB_3_2, KiKit_MB_3_3, KiKit_MB_3_4, KiKit_MB_4_1, KiKit_MB_4_2, KiKit_MB_4_3, KiKit_MB_4_4, KiKit_MB_5_1, KiKit_MB_5_2, KiKit_MB_5_3, KiKit_MB_5_4, KiKit_MB_6_1, KiKit_MB_6_2, KiKit_MB_6_3, KiKit_MB_6_4, KiKit_MB_7_1, KiKit_MB_7_2, KiKit_MB_7_3, KiKit_MB_7_4, KiKit_MB_8_1, KiKit_MB_8_2, KiKit_MB_8_3, KiKit_MB_8_4, KiKit_MB_9_1, KiKit_MB_9_2, KiKit_MB_9_3, KiKit_MB_9_4, KiKit_MB_10_1, KiKit_MB_10_2, KiKit_MB_10_3, KiKit_MB_10_4, KiKit_MB_11_1, KiKit_MB_11_2, KiKit_MB_11_3, KiKit_MB_11_4, KiKit_MB_12_1, KiKit_MB_12_2, KiKit_MB_12_3, KiKit_MB_12_4, KiKit_MB_13_1, KiKit_MB_13_2, KiKit_MB_13_3, KiKit_MB_13_4, KiKit_MB_14_1, KiKit_MB_14_2, KiKit_MB_14_3, KiKit_MB_14_4, KiKit_MB_15_1, KiKit_MB_15_2, KiKit_MB_15_3, KiKit_MB_15_4, KiKit_MB_16_1, KiKit_MB_16_2, KiKit_MB_16_3, KiKit_MB_16_4, KiKit_MB_17_1, KiKit_MB_17_2, KiKit_MB_17_3, KiKit_MB_17_4, KiKit_MB_18_1, KiKit_MB_18_2, KiKit_MB_18_3, KiKit_MB_18_4, KiKit_MB_19_1, KiKit_MB_19_2, KiKit_MB_19_3, KiKit_MB_19_4, KiKit_MB_20_1, KiKit_MB_20_2, KiKit_MB_20_3, KiKit_MB_20_4, KiKit_MB_21_1, KiKit_MB_21_2, KiKit_MB_21_3, KiKit_MB_21_4, KiKit_MB_22_1, KiKit_MB_22_2, KiKit_MB_22_3, KiKit_MB_22_4, KiKit_MB_23_1, KiKit_MB_23_2, KiKit_MB_23_3, KiKit_MB_23_4, KiKit_MB_24_1, KiKit_MB_24_2, KiKit_MB_24_3, KiKit_MB_24_4, KiKit_MB_25_1, KiKit_MB_25_2, KiKit_MB_25_3, KiKit_MB_25_4, KiKit_MB_25_5, KiKit_MB_25_6, KiKit_MB_25_7, KiKit_MB_26_1, KiKit_MB_26_2, KiKit_MB_26_3, KiKit_MB_26_4, KiKit_MB_26_5, KiKit_MB_26_6, KiKit_MB_26_7, KiKit_MB_27_1, KiKit_MB_27_2, KiKit_MB_27_3, KiKit_MB_27_4, KiKit_MB_27_5, KiKit_MB_27_6, KiKit_MB_27_7, KiKit_MB_28_1, KiKit_MB_28_2, KiKit_MB_28_3, KiKit_MB_28_4, KiKit_MB_28_5, KiKit_MB_28_6, KiKit_MB_28_7, KiKit_MB_29_1, KiKit_MB_29_2, KiKit_MB_29_3, KiKit_MB_29_4, KiKit_MB_29_5, KiKit_MB_29_6, KiKit_MB_29_7, KiKit_MB_30_1, KiKit_MB_30_2, KiKit_MB_30_3, KiKit_MB_30_4, KiKit_MB_30_5, KiKit_MB_30_6, KiKit_MB_30_7, KiKit_MB_31_1, KiKit_MB_31_2, KiKit_MB_31_3, KiKit_MB_31_4, KiKit_MB_31_5, KiKit_MB_31_6, KiKit_MB_31_7, KiKit_MB_32_1, KiKit_MB_32_2, KiKit_MB_32_3, KiKit_MB_32_4, KiKit_MB_32_5, KiKit_MB_32_6, KiKit_MB_32_7: NPTH
KiKit_TO_1, KiKit_TO_2, KiKit_TO_3, KiKit_TO_4: NPTH
U1, U1#2, U1#3, U1#4, U1#5, U1#6: TMAG5273A1QDBVT; DBV0006A-IPC_A

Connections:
Board_0-+3V3: C1#4.1, J3#4.1, U1#4.4 (VCC)
Board_0-GND: C1#4.2, J3#4.4, U1#4.2 (TEST), U1#4.3 (GND), U1#4.5 (INT_N)
Board_0-SCA: J3#4.2, U1#4.6 (SDA)
Board_0-SCL: J3#4.3, U1#4.1 (SCL)
Board_1-+3V3: C1#3.1, J3#2.1, U1.4 (VCC)
Board_1-GND: C1#3.2, J3#2.4, U1.2 (TEST), U1.3 (GND), U1.5 (INT_N)
Board_1-SCA: J3#2.2, U1.6 (SDA)
Board_1-SCL: J3#2.3, U1.1 (SCL)
Board_2-+3V3: C1#5.1, J3.1, U1#2.4 (VCC)
Board_2-GND: C1#5.2, J3.4, U1#2.2 (TEST), U1#2.3 (GND), U1#2.5 (INT_N)
Board_2-SCA: J3.2, U1#2.6 (SDA)
Board_2-SCL: J3.3, U1#2.1 (SCL)
Board_3-+3V3: C1#6.1, J3#5.1, U1#6.4 (VCC)
Board_3-GND: C1#6.2, J3#5.4, U1#6.2 (TEST), U1#6.3 (GND), U1#6.5 (INT_N)
Board_3-SCA: J3#5.2, U1#6.6 (SDA)
Board_3-SCL: J3#5.3, U1#6.1 (SCL)
Board_4-+3V3: C1#2.1, J3#6.1, U1#5.4 (VCC)
Board_4-GND: C1#2.2, J3#6.4, U1#5.2 (TEST), U1#5.3 (GND), U1#5.5 (INT_N)
Board_4-SCA: J3#6.2, U1#5.6 (SDA)
Board_4-SCL: J3#6.3, U1#5.1 (SCL)
Board_5-+3V3: C1.1, J3#3.1, U1#3.4 (VCC)
Board_5-GND: C1.2, J3#3.4, U1#3.2 (TEST), U1#3.3 (GND), U1#3.5 (INT_N)
Board_5-SCA: J3#3.2, U1#3.6 (SDA)
Board_5-SCL: J3#3.3, U1#3.1 (SCL)

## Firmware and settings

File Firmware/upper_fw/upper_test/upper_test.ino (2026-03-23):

/*
* Upper LC Board Testing Firmware
* Authors: Jeevan Sanchez, Tristan Alderson
* Hardware: Upper Launch-Control Board (ESP32-S3)
* Created: February 2026
* Overview: Valve Ctrl, ADC, WiFi, LED testing for the upper lc board. (CAN testing not implemented yet.)

** Av/Propulsion Integration 
*/

#include <Arduino.h>
#include <ADS131M04.h>
#include <SPI.h>
#include <WiFi.h>
#include <esp_adc_cal.h>

const int8_t ADC_MOSI = 11;
const int8_t ADC_MISO = 13;
const int8_t ADC_CLKIN = 18;
const int8_t ADC_SCLK = 12;
const int8_t ADC_CS = 0;

const int valveEN1 = 9;
const int valveEN2 = 3;
const int TEMP_SENSE = 10;

int leds[] = {35, 36, 37, 48, 40, 41, 42};
const int ledCount = 7;
const int wifiLed = 40;

const float ADCVRef = 1.2;
const float ADCresFactor = 8388608.0; // 2^23
const float shuntResistance = 165.0;
const float maxPSI = 100; // needs to be double-checked

// FILL IN - wifi credentials
const char* ssid = "";
const char* pswd = "";

// Thermistor (cold junction) constants 
// Ohmite TX Series NTC thermistor on pin 10
// Assumes voltage divider: 3.3V -> R_SERIES -> NTC -> GND
// Confirm R_SERIES matches your board's pull-up resistor
const float THERM_R_SERIES  = 10000.0;  // series resistor (Ohms)
const float THERM_R0        = 10000.0;  // thermistor resistance at 25°C (Ohms)
const float THERM_B         = 3435.0;   // B-value (K) — TX06F103F3435ER / TX08F103F3435ER
const float THERM_T0        = 298.15;   // 25°C in Kelvin
const float ESP32_VREF      = 3.3;
const float ESP32_ADC_RES   = 4095.0;   // 12-bit

// --- K-type thermocouple constants ---
// CH0 on the ADS131M04 is a K-type thermocouple
// Seebeck coefficient for K-type: ~41.276 µV/°C (linear approx, valid -200 to +1372°C)
const float K_TYPE_SEEBECK_UV_PER_C = 41.276; // µV / °C

ADS131M04 adc(ADC_CS, ADC_CLKIN, &SPI, 1);

void adcSetup() {
    SPI.begin(ADC_SCLK, ADC_MISO, ADC_MOSI, ADC_CS);
    adc.begin(); 
    delay(100);
    adc.setGain(0, 0, 0, 0);
}

void blinkLed(int ledPin, int ms) {
    digitalWrite(ledPin, HIGH);
    delay(ms);
    digitalWrite(ledPin, LOW);
    delay(ms);
}

void wifiTest(const char* ssid, const char* pswd) {
    Serial.printf("\nconnecting to: %s\n", ssid);
    WiFi.begin(ssid, pswd); 

    int timeout_idx = 0;
    while (WiFi.status() != WL_CONNECTED) {
        delay(500);
        blinkLed(wifiLed, 300);
        Serial.print(".");
        timeout_idx++;
        if (timeout_idx=10)
          break;
    }c:\Users\jeeva\Documents\dev\homectrl-sys\firmware\test\test.ino

    if (WiFi.status() == WL_CONNECTED) {
        Serial.printf("\connected to: %s\n", ssid);
        digitalWrite(wifiLed, HIGH);
    } else {
        Serial.println("\nFailed to connect.");
    }
}

void valveControl(const int valvePin) {
    digitalWrite(valvePin, HIGH);
    Serial.println("solenoid ON");
    delay(2000);
    digitalWrite(valvePin, LOW);
    Serial.println("solenoid OFF");
}

void flashLeds(const int ledArray[], int count) {
    for (int i = 0; i < count; i++) {
        Serial.printf("flashing LED on GPIO %d\n", ledArray[i]);
        digitalWrite(ledArray[i], HIGH);
        delay(800);
        digitalWrite(ledArray[i], LOW);
    }
}

float rawToVoltage(int32_t reading) {
    float voltage = (reading / ADCresFactor) * ADCVRef; 
    return voltage; 
}

// likely will be implemented with more filtering
float voltageToPSI(float voltage) {
    float currentMA = (voltage / shuntResistance) * 1000;
    float psiReading = (currentMA - 4.0) * (maxPSI / 16.0); // P = (I - I_min) * (P_max / (I_max - I_min))
    if (psiReading < 0) psiReading = 0; 

    return psiReading;
}

void readADC(int32_t* outputBuffer) {
    int8_t allChannels[] = {0, 1, 2, 3};
    adc.rawChannels(allChannels, 4, outputBuffer);
}

// Uses the Steinhart-Hart B-parameter equation:
//   1/T = 1/T0 + (1/B) * ln(R / R0)
// Returns temperature in Celsius.
float readColdJunction() {
    uint32_t raw = analogRead(TEMP_SENSE);

    // Convert ADC count to thermistor resistance via voltage divider
    float vOut = (raw / ESP32_ADC_RES) * ESP32_VREF;           // voltage at pin
    float rTherm = THERM_R_SERIES * vOut / (ESP32_VREF - vOut); // NTC resistance (Ω)

    // B-parameter equation -> temperature in Kelvin
    float tKelvin = 1.0 / (1.0 / THERM_T0 + (1.0 / THERM_B) * log(rTherm / THERM_R0));

    return tKelvin - 273.15; // convert to Celsius
}

// --- K-type Thermocouple Temperature (CH0) ---
// cold junction compensation (CJC):
//   T_hot = T_cold + (V_tc / Seebeck)
// voltage in Volts, returns temperature in Celsius.
float voltageToThermocouple(float voltage, float coldJunctionCelsius) {
    float voltageMicroV = voltage * 1e6;                               // V -> µV
    float deltaTemp     = voltageMicroV / K_TYPE_SEEBECK_UV_PER_C;    // µV / (µV/°C) = °C
    return coldJunctionCelsius + deltaTemp;
}

void setup() {
    Serial.begin(9600);
    delay(1000);
    Serial.println("start upper-lc-board testing");
    Serial.println("1: solenoid 1 | 2: solenoid 2 | 3: LEDs | 4: ADC | 5: TEMP | 6: WiFi");

    pinMode(valveEN1, OUTPUT);
    pinMode(valveEN2, OUTPUT);
    digitalWrite(valveEN1, LOW);
    digitalWrite(valveEN2, LOW);

    pinMode(TEMP_SENSE, INPUT);

    pinMode(wifiLed, OUTPUT); 
    digitalWrite(wifiLed, LOW); // on by default, so explicitly turn it off til needed

    for (int i = 0; i < ledCount; i++) {
        pinMode(leds[i], OUTPUT);
        digitalWrite(leds[i], LOW);
    }

    adcSetup();
}

void loop() {
    if (Serial.available() > 0) {
        char input = Serial.read();
        int32_t adcResults[4] = {0, 0, 0, 0};
        uint32_t temp_sense = 0;

        switch (input) {
            case '1':
                valveControl(valveEN1);
                break;

            case '2':
                valveControl(valveEN2);
                break;

            case '3':
                flashLeds(leds, ledCount);
                break;

            case '4': {
                readADC(adcResults);
                float coldJunctionC = readColdJunction(); // read CJC once before ADC loop

                Serial.println("ADC Readings:");
                for (int i = 0; i < 4; i++) {
                    float volts = rawToVoltage(adcResults[i]);

                    if (i == 0) {
                        // CH0: K-type thermocouple with cold junction compensation
                        float tempC = voltageToThermocouple(volts, coldJunctionC);
                        Serial.printf("CH%d: %.4f V | %7.2f °C (K-type TC, CJC: %.2f °C)", i, volts, tempC, coldJunctionC);
                    } else {
                        // CH1-3: pressure transducers
                        float psi = voltageToPSI(volts);
                        Serial.printf("CH%d: %.4f V | %7.2f PSI", i, volts, psi);
                    }
                    Serial.println();
                }
                break;
            }

            case '5':
                temp_sense = analogRead(TEMP_SENSE);
                Serial.printf("Temp analog raw: %d", temp_sense);
                Serial.println();
                {
                    float cjTemp = readColdJunction();
                    Serial.printf("Cold junction: %.2f °C", cjTemp);
                    Serial.println();
                }
                break;

            case '6':
                wifiTest(ssid, pswd); 
                break;

            default:
                Serial.println("uh");
                break;
        }
    }
}

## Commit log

2026-01-12 add requested changes for PR
    [PT_module.kicad_sch, TC_module.kicad_sch, VALVE_control.kicad_sch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]
2026-01-14 add all circuitry and missing datasheets
    [PT_module.kicad_sch, STM32_breakout_module.kicad_sch, TC_module.kicad_sch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]
2026-01-18 pin assignments verified
    [PT_module.kicad_sch, STM32_breakout_module.kicad_sch, VALVE_control.kicad_sch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]
2026-01-18 start layout
    [S02B-PASK-2.stp, S04B-PASK-2.STEP, STM32_breakout_module.kicad_sch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]
2026-01-18 replace sensing LEDs with a single
    [STM32_breakout_module.kicad_sch, lower_lc_board.kicad_pcb, sensing_module.kicad_sch]
2026-01-18 quick changes
    [XE-1139-001.stp, lower_lc_board.kicad_pcb]
2026-01-18 init commit of board that provides 24V for testing
    [dummy_24v_board.kicad_pcb, dummy_24v_board.kicad_sch]
2026-01-18 layout work
    #TODO
    - smaller 3V3 buck, add HF cap
    - finish layout
    [STM32_breakout_module.kicad_sch, TC_module.kicad_sch, W25Q128JVSIM.step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]
2026-01-18 Board setup with footprint
    [dummy_24v_board.kicad_sch]
2026-01-20 layout work
    [STM32_breakout_module.kicad_sch, lower_lc_board.kicad_pcb]
2026-01-20 add sensing circuitry layout
    [lower_lc_board.kicad_pcb]
2026-01-20 finish layout
    - model paths need to be fixed
    - waiting for confirmation for shared folders
    [PT_module.kicad_sch, TC_module.kicad_sch, lower_lc_board.kicad_pcb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]
2026-01-22 added 3.3V,5V,CAN
    [dummy_24v_board.kicad_pcb]
2026-01-22 add power switching for PTs (schematic only)
    [PT_module.kicad_sch, STM32_breakout_module.kicad_sch, VALVE_control.kicad_sch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]
2026-01-26 more layout work, add testing code
    [STM32_breakout_module.kicad_sch, lower_lc_board.kicad_pcb, power_module.kicad_sch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]
2026-01-26 add buzzer circuitry, some layout work
    [STM32_breakout_module.kicad_sch, lower_lc_board.kicad_pcb, sensing_module.kicad_sch]
2026-01-27 some routing work
    [STM32_breakout_module.kicad_sch, lower_lc_board.kicad_pcb, m20-8890445r.stp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]
2026-01-28 CAN, JTAG & I2C routing
    [lower_lc_board.kicad_pcb]
2026-01-28 start power routing
    [STM32_breakout_module.kicad_sch, lower_lc_board.kicad_pcb]
2026-01-28 added two TestPoints for BATT 1&2
    [dummy_24v_board.kicad_pcb, dummy_24v_board.kicad_sch]
2026-01-29 quick push
    [lower_lc_board.kicad_pcb]
2026-01-29 quick revert for layout cleanup
    [CP2102N-A02-GQFN20.STEP, STM32_breakout_module.kicad_sch, lower_lc_board.kicad_pcb]
2026-01-30 add new package to schwmatic
    [STM32_breakout_module.kicad_sch]
2026-01-31 organizational work
    [0679L0250-05.step, 10118194-0001LF-USB.step, 282834-3.step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]
2026-02-01 more organizational work, add shared footprint, model, symbol dirs and clean up individuals
    [0679L0250-05.step, 10118194-0001LF-USB.step, 282834-3.step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]
2026-02-01 routing work
    [5019390300.stp, BLM31KN121SN1L.step, PT_module.kicad_sch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]
2026-02-01 gnd vias added
    [dummy_24v_board.kicad_pcb]
2026-02-01 Vias modified
    [dummy_24v_board.kicad_pcb]
2026-02-01 Connectors model added
    [CONN_2-1445057-2_AMP.step, dummy_24v_board.kicad_pcb, dummy_24v_board.kicad_sch]
2026-02-03 via sizes changed
    [dummy_24v_board.kicad_pcb]
2026-02-03 cleanup PCB, switch to solid copper pour, add GND tp, and updated silkscreen
    [dummy_24v_board.kicad_pcb, dummy_24v_board.kicad_sch]
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2026-02-04 single finished hall effect
    -need to fix connector step orientation
    [B04B-PASK.STEP, TMAG5273A1QDBVT.stp, hall_effect_board.kicad_pcb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]
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2026-02-07 analog routing, start 3V3 power routing
    [STM32_breakout_module.kicad_sch, actuation_module.kicad_sch, lower_lc_board.kicad_pcb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]
2026-02-08 more 3v3 routing
    - considering ground pour on f.cu for mosfet src
    - reconsidering multiple gnd nets
    [lower_lc_board.kicad_pcb]
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2026-02-12 ADC testing
    - update testing FW with new ADC lib
    - switched 165 shunt resistor to 60 based on fixed calculations
    [PT_module.kicad_sch, TC_module.kicad_sch]
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2026-02-20 adjust routing for 0603 min. footprints
    [PT_module.kicad_sch, STM32_breakout_module.kicad_sch, TC_module.kicad_sch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]
2026-02-21 more local pours and 0402 adjustments
    [STM32_breakout_module.kicad_sch, actuation_module.kicad_sch, lower_lc_board.kicad_pcb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]
2026-02-25 review of schematics and pcb
    - verified all STM pins
    - reviewed all circuits
    - reviewed trace clearences, made sure routes are connected, etc.
    [ESP_breakout_module.kicad_sch, PT_module.kicad_sch, STM32_breakout_module.kicad_sch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]
2026-02-26 WIP-commit: remove surge prot, move TH to back-side.
    [STM32_breakout_module.kicad_sch, lower_lc_board.kicad_pcb]
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2026-02-28 put TH on backside, add edge-vias
    [lower_lc_board.kicad_pcb, power_module.kicad_sch]
2026-02-28 finalize additional gnd hole
    - added a tht gnd TP in addition to pad for easier testingr
    [lower_lc_board.kicad_pcb]
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2026-03-01 start of review for lower control board, Cleaning up power and spi traces
    [lower_lc_board.kicad_pcb]
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2026-03-05 updates to dummy board for splitting A and B power and new edge connector
    [dummy_24v_board.kicad_pcb, dummy_24v_board.kicad_sch]
2026-03-07 Updated PCB layout with new 3.3V_B connector
    [dummy_24v_board.kicad_pcb]
2026-03-10 3.3V_B flipped to front & Gn2 trace added
    [dummy_24v_board.kicad_pcb]
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2026-03-11 pmux fix
    [lower_lc_board.kicad_pcb]
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2026-03-11 final updates before putting in cart
    [dummy_24v_board.kicad_pcb]
2026-03-12 Single hall effect sensor with fixed via and text
    [hall_effect_panel_Mar11.kicad_pcb]
2026-03-12 Completed hall effect panel with fixed vias
    [hall_effect_panel_Complete.kicad_pcb]
2026-03-16 increase width on power rails from USB and SWD, start tuning diff pairs
    [PT_module.kicad_sch, STM32_breakout_module.kicad_sch, TC_module.kicad_sch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]
2026-03-18 cleaned up hall effect, switched to plated through holes
    [hall_effect_board.kicad_pcb, hall_effect_board.kicad_sch, hall_effect_panel_Mar11.kicad_pcb]
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2026-03-19 Update LLibraryfor 3.3v Line B
    [dummy_24v_board.kicad_sch]
2026-03-23 organize working copy of lower valve board for merge to main
    [PT_module.kicad_sch, STM32_breakout_module.kicad_sch, TC_module.kicad_sch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]
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2026-03-26 Hall effect panel for updated connector
    [hall_effect_panel.kicad_pcb]
2026-03-28 update schematic pin names
    [hall_effect_board.kicad_sch, lower_lc_board.kicad_pcb]
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2026-05-10 Found issue on hall board, only effects LED
    [hall_effect_board.kicad_pcb, hall_effect_board.kicad_sch, hall_effect_panel.kicad_pcb]
